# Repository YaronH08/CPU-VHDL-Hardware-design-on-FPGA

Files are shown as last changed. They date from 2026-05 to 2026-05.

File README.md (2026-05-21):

# Processor Architecture and RTL Design

## Overview

This repository contains an academic laboratory project focused on processor architecture, RTL design, and hardware description methodologies.

The lab demonstrates the design and analysis of core processor components, with emphasis on the relationship between the instruction set architecture, the datapath, and the control unit. The project was implemented as part of a Hardware Description Languages and FPGA-based digital design course.

The main goal of this lab was to gain practical experience in designing digital hardware at the RTL level and understanding how processor functionality is translated into hardware structures.

---

## Main Objectives

- Understand the basic structure of a processor core
- Study the relationship between ISA and microarchitecture
- Design processor components using RTL methodology
- Analyze the separation between datapath and control logic
- Perform functional simulation and verification
- Gain practical experience with hardware description languages

---

## Key Topics

- Hardware Description Languages
- RTL design methodology
- Processor architecture
- ISA and microarchitecture concepts
- Datapath design
- Control-unit logic
- Functional verification
- Testbench-based simulation

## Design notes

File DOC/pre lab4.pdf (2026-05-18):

# Preparation Report LAB4

## דביר חן סעד 214078792-

## ירון חדד- 316411057

## תוכן עניינים

בדיקת ביצועים | 3.

### סימולציה | 4-6

מציאת תדר מקסימלי | 7.
תיאור המערכת | 8-10.
הצגת הרכיבים RTL ומסלול קריטי | 10-16.
שימוש בסיגנלים | 17..

# מטרת המעבדה

במעבדה זו נלמד כיצד לבצע סינתזה עבור מודלים שאנו נפתח בעזרת תוכנת Quartus

ובפרט נשתמש במודל אשר פיתחנו במעבדה 1 ונוסיף לו עוד מודל סינכרוני אשר מוגדר

בהמשך.

את הסינתזה נבצע על FPGA v cyclone.

בנוסף למודל של מעבדה 1 התבקשנו להוסיף עוד מודל סינכורני אשר מייצר לנו גלי PWM לפי קוד הALU המבוקש.

את הרכיב ממישנוב בעזרת מונה)counter )ויחידה לוגית אשר אחראית למימוש הגלים.

להלן המודל אותו ממשנו בתמונה מס1

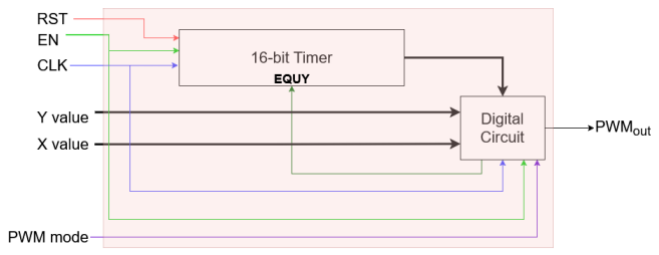
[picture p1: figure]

תמונה 1 מעטפת למודל הPWM

בדיקת ביצועים

בכדי לבדוק את הביצועים של המודל אשר פיתחנו במעבדה 1 אך בכדי לבצע סינתה נצטרך רכיב סינכרוני אך הרכיב של מעבדה 1 לא סינכרוני ולכן נוסיף באופן מלאכותי מערכת סינכרונית של רגיסטר כניסה ורגיסטר מוצא אשר הם יפעלו לפי אותו שעון.

כפי שמוצג בתמונה מס 2

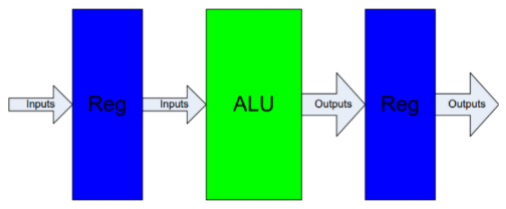
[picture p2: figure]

תמונה 2 מעטפת למודל הALU

כאשר אל הרגיסטרים מחובר השעון של הכרטיס -

signal name | FPGA Pin No | Description | I/O Standard
CLOCK_50 | PIN_AF14 | 50MHz clk input | 3.3V

Model-sim | סימולציית

### בסימולציה זו ניצור TB אשר יבדוק את המודל באופן פרטני עבור כל מודל כאשר

הכל עטוף במעטפת של הtop.

### נסתכל על מספר של בדיקות ונראה שאכן מתבצע כמצופה פעולת add

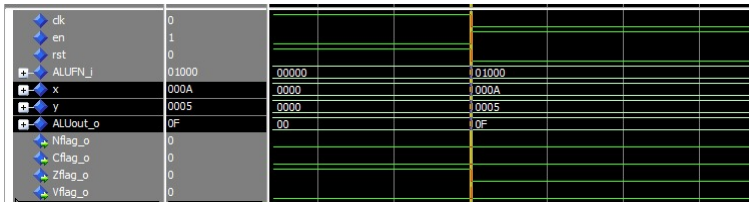
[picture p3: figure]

תמונה 3 תוצאת פעולת החיבור

### כפי שאנו רואים ערכי הרגיסטר X וערך הרגיסטר Y נסכמים ואכן אנו מקבלים את התוצאה הרצויה F=+5A כלומר 10+5=15

### פעולת Logic

תמונה 4 פעולת logic
אנו רואים כי קוד הפעולה 010 הינו פעולת הand ואנו רואים כי רק ביט הMSB והביט ה4 דולקים אצל שני הכניסות ואכן תוצאת הפעולה היא שיש 1 רק עבור 2 הביטים הנ"ל

### פעולת SHL

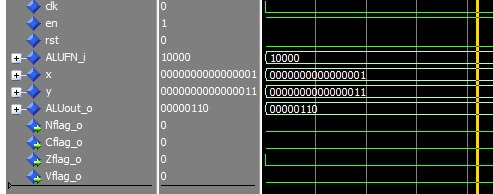
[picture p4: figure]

תמונה 5 תוצאת פעולת הזזה

### נשים לב כי אותות הכניסה הינם 1 ו3 כלומר ערך המוזז הינו 3 ואנו נצטרך לבצע הזזה אחת כלומר -011< 110 כלומר נצפה לקבל את הערך 6 ואכן המוצא הינו .6

### פעולת PWM

תמונה 6 תוצאת פעולת אות pwm

כפי שניתן לראות קוד הפעולה הינו 00001 כלומר כפי שהוגדר הגל אמור לעלות בערך y ולרדת כאשר אנו מגיעים לערך x
במצב שלנו c=y3,=x ואכן אנו רואים כי בזמן הגעת השעון לערך c האות עולה ל1 ונשאר על הערך 1 עד הגעת השעון לערך .3

## מציאת תדר מקסימלי

### בכדי למצוא את התדר המקסימלי של המערכת שלנו כמו שהזכרנו למעלה הוספנו 2

רגיסטרים בכניסה ובמוצא של מודל הalu. כעת נבצע קימפול וסינתזה של הרכיב כפי שמבוקש .

### לאחר הקימפול נוכל להכנס לTool ולאחר מכן לבחור את האופציה שלtimer ושם יש לנו את העמודה שמראה מהו התדר המקסימלי:

תמונה 7 מציאת התדר המקסימלי של המודל

לאחר שמצאנו את התדר הנ"ל נצטרך להציב אותו במערכת כדי ליצור חסם על התדר בכדי לא לחרוג מהמערכת וגם בכדי לא לבזבז הספק לחינם.

## תיאור המערכת

### המערכת שלנו מפוצלת ל2 חלקים נפרדים כאשר כל מודול מורכב מתתי רכיבים

כעת נפרק מה הלוגיקה של כל אחד מהם ונראה את הסינתזה שלהם בעזרת תוכנת | -
רכיב הSDC –רכיב סינכרוני אשר פועל בזמן של עליית שעון | -

### רכיב הalu – רכיב אסינכרוני אשר פועל ללא תלות בשעון

הQuartus.

## רכיב הALU

### נרצה לממש מערכת אשר מבצעת מספר של פעולות כאשר לכל פעולה יש קוד

פעולה ספציפי אשר מגדיר מתי נשתמש בה .

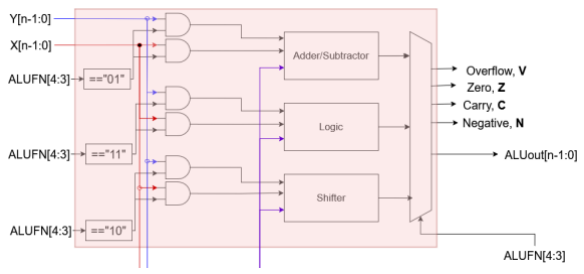
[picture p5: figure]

תמונה 8 מודל הALU
המודל מקבל 3 כניסות
- X- כניסה בעלת 16 ביטים
- Y -כניסה בעלת 16 ביטים
- ALUFN -קו בקרה בעל 5 סיביות שמגדיר את הפעולה שצריך לבצע

מוצאי המערכת הם:
- דגלים Nflag,Zflag,Vflag,Cflag- שמופעלים בהתאם לתוצאה של הפעולה שהתבצעה .
- ALUOUT מוצא בעל 16 סיביות שהוא התוצאה של הפעולה על x ועל y.

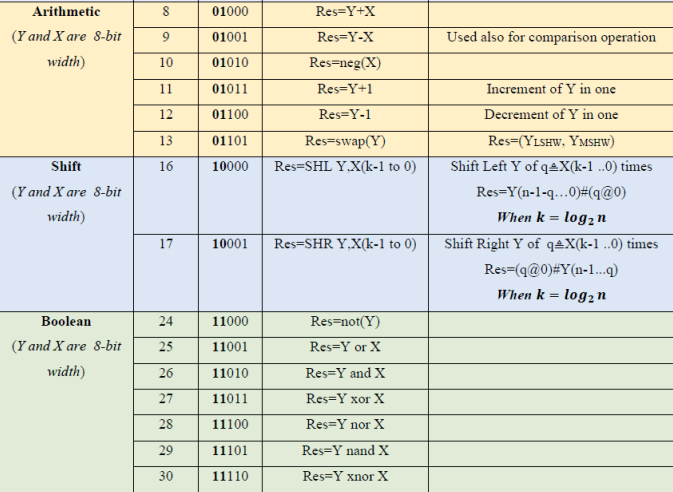
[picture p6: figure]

תמונה 9 הפעולות אשר ממושמות במודל שלALU

## רכיב הPWM

### רכיב בעל 6 כניסות

- X- כניסה בעלת 16 ביטים
- Y -כניסה בעלת 16 ביטים
- ALUFN -קו בקרה בעל 5 סיביות שמגדיר את הפעולה שצריך לבצע
- קוי בקרה Rst,En שאחראיים על תקפוד המערכת
- כניסת שעון clk

מוצאי המערכת הם:
- אות PWM שעליתו וירידתו הם כתוצאה מY,X וקוד הפעולה

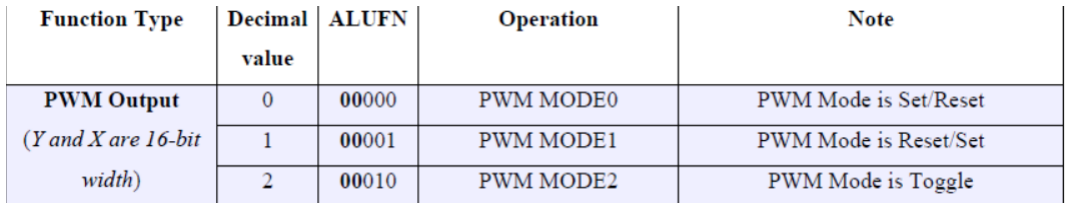
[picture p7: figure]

תמונה 10 הפעולות אשר ממושמות במודל שלPWM

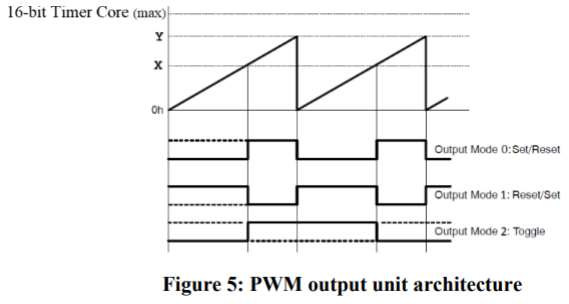
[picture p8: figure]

תמונה 11 סוגי הגלים אשר יוצאים מתוך המודולו כתלות בcounter

# שרטוט הRTL

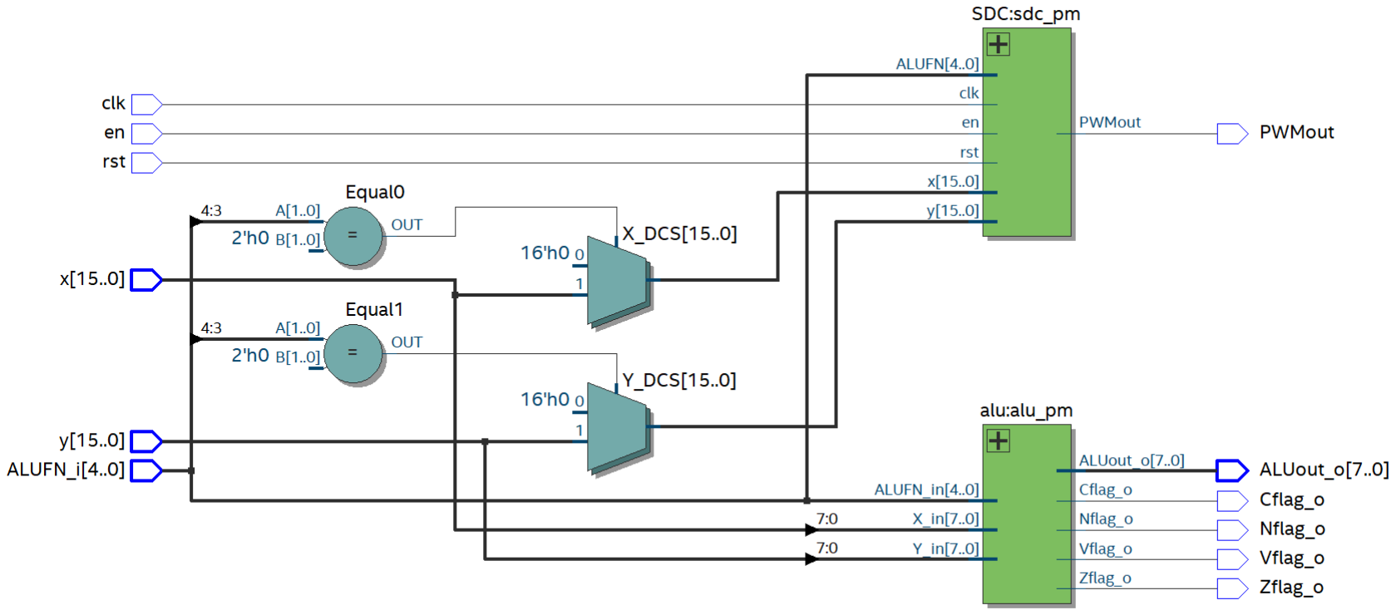
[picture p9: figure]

תמונה 11 RTL של המערכת הכוללת אפשר לראות שהמערכת מורכבת מ2 רכיבים אחד סינכרוני ואחד אסינכרוני כאשר יש mux שבורר בין 0 לערכי הכניסות וזה בכדי לשמור על בזבוז ההספק של המערכת. בזמן שהרכיב לא משומש נכנס הערכים 0000 בכל כניסה.

## רכיב AdderSub

רכיב זה מומש כבר במעבדה 1 ולכן רק נציג את התוספות שתורמת לנו התוכנה של הQuartus

## שרטוט הRTL

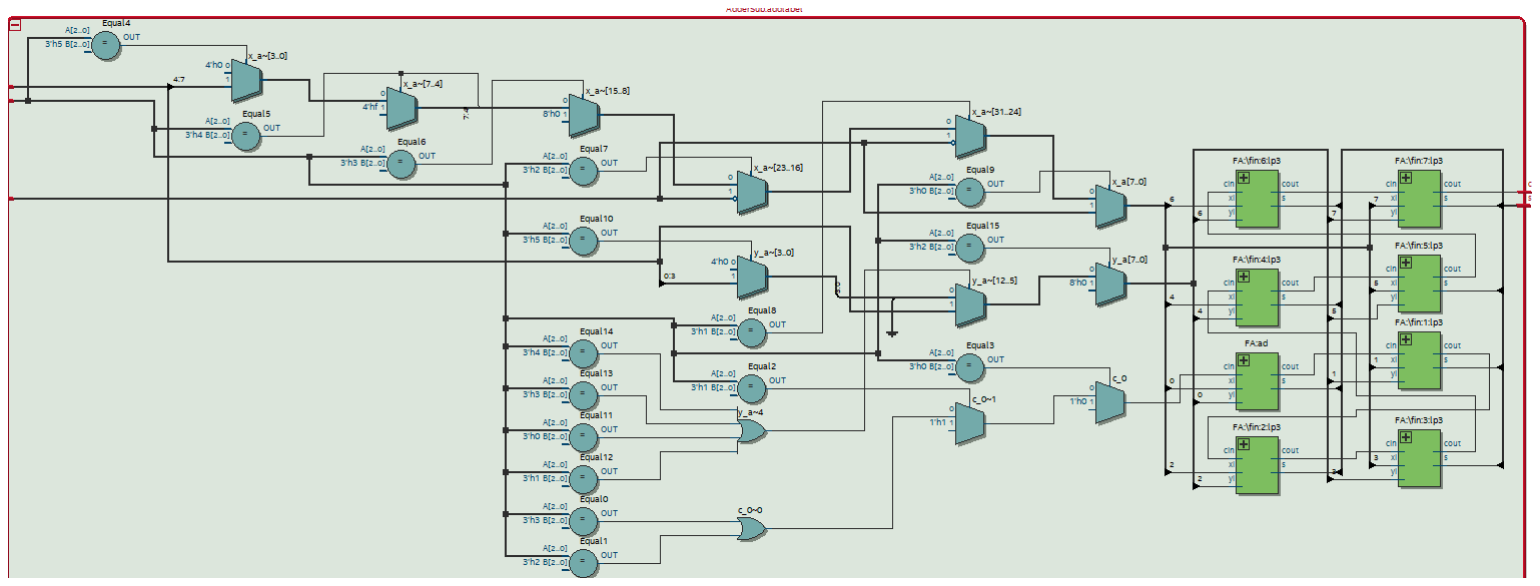
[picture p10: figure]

תמונה 12 RTL של הaddersub

## שימוש בלוגיקה כאשר פיתחנו את הקוד הלוגי אנו משתמשים באלמנטים הניתנים לקינפוג בהתאם לקוד הכתוב, בעזרת הקוארטוס בזמן תהליך הסינתזה אפשר להראות את הלוגיה של הרכיב:

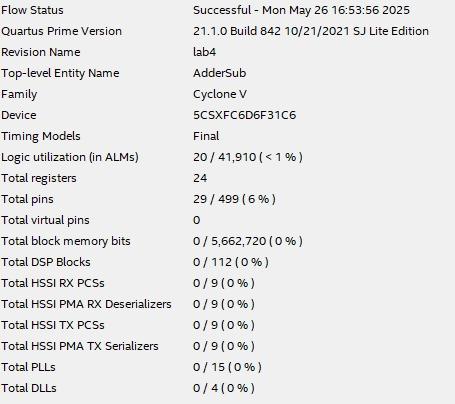
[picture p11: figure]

תמונה 13 לוגיה של הaddersub

## נתיב קריטי

הנתיב הקריטי חשוב ביותר מכיוון שהוא נותן לנו מידע על הזרימה של המידע וגם נותן לנו מגבלות עליה
מכיוון שלרכיבים יש השהייה עד להתייצבות הכניסות נצטרך לקחת זאת בחשבון להלן הנתיב הקריטי :

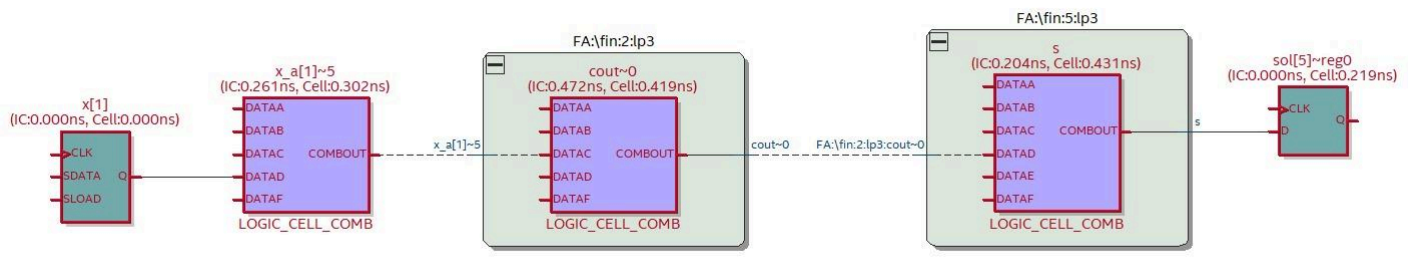
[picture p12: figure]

תמונה 14 נתיב קריטי של הaddersub

## רכיב Logic

רכיב זה מומש כבר במעבדה 1 ולכן רק נציג את התוספות שתורמת לנו התוכנה של הQuartus

## שרטוט הRTL

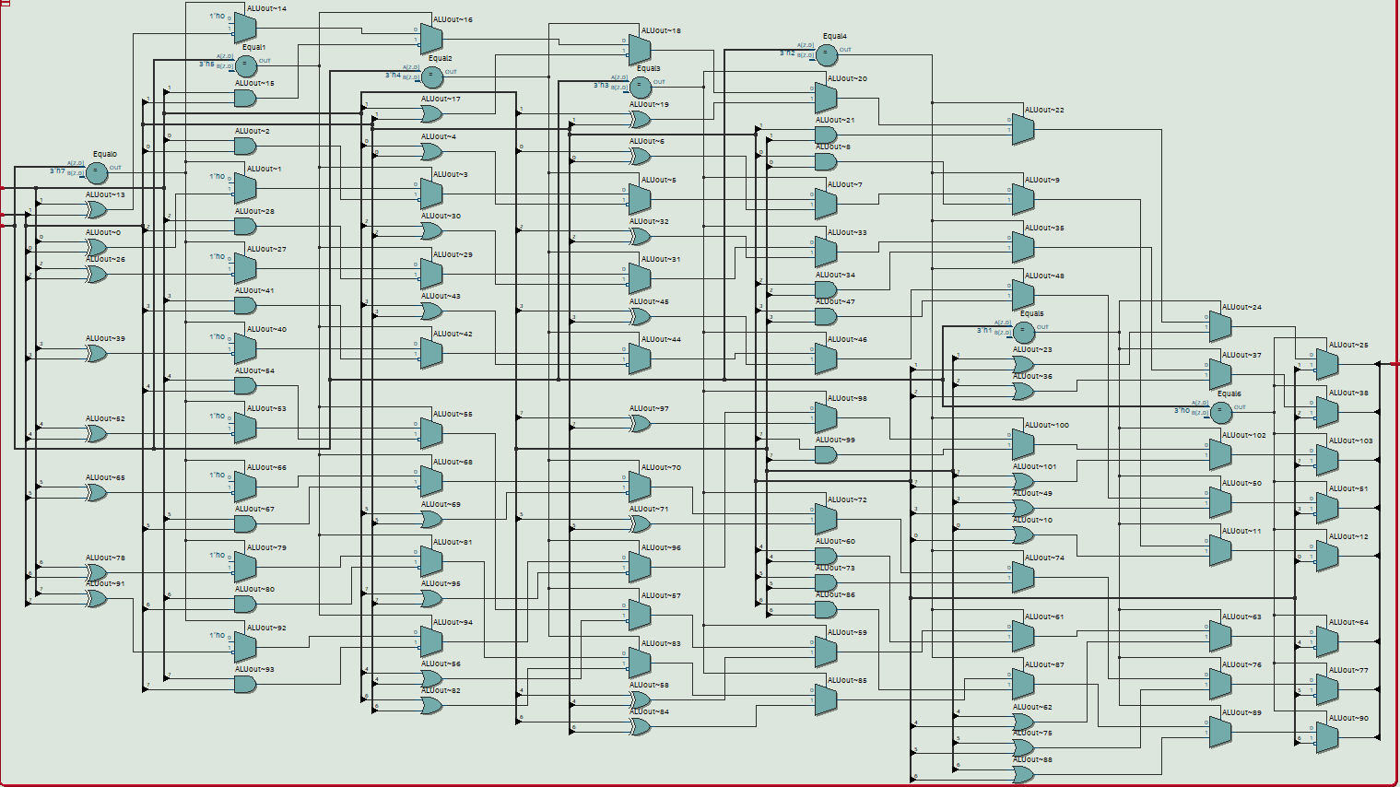
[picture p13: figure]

תמונה 15 RTL של הlogic

## שימוש בלוגיקה

כאשר פיתחנו את הקוד הלוגי אנו משתמשים באלמנטים הניתנים לקינפוג בהתאם לקוד הכתוב, בעזרת הקוארטוס בזמן תהליך הסינתזה אפשר להראות את הלוגיה של הרכיב:

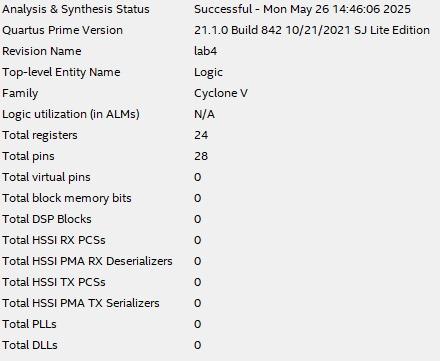
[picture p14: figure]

תמונה 16 לוגיה של logic

## נתיב קריטי

הנתיב הקריטי חשוב ביותר מכיוון שהוא נותן לנו מידע על הזרימה של המידע וגם נותן לנו מגבלות עליה
מכיוון שלרכיבים יש השהייה עד להתייצבות הכניסות נצטרך לקחת זאת בחשבון להלן הנתיב הקריטי :

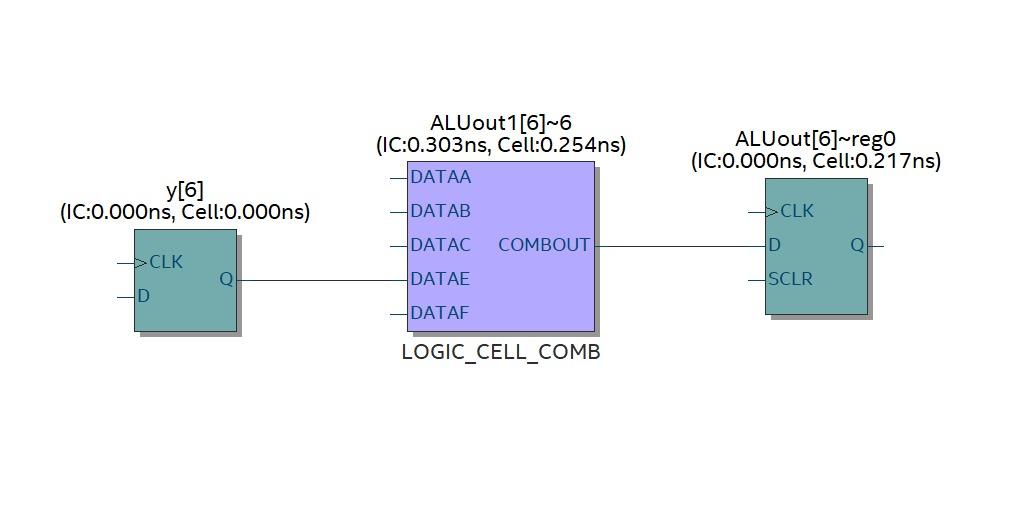
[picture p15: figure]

תמונה 17 נתיב קריטי של הlogic

## רכיב Shifter

רכיב זה מומש כבר במעבדה 1 ולכן רק נציג את התוספות שתורמת לנו התוכנה של הQuartus

## שרטוט הRTL

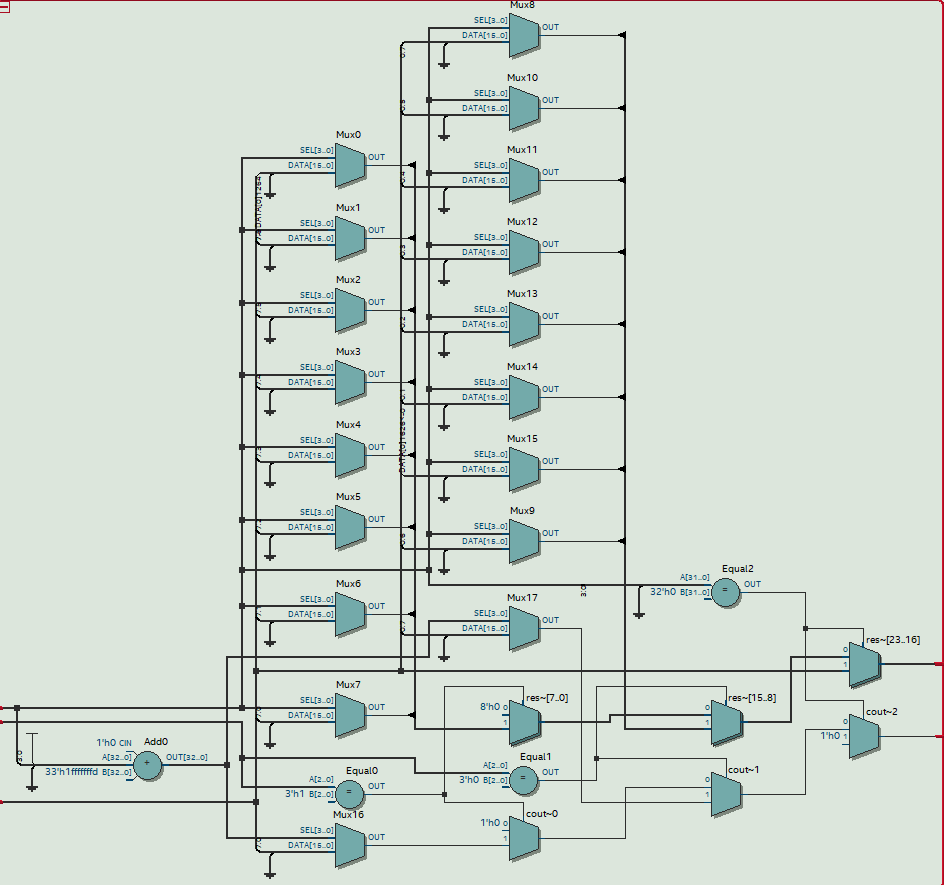
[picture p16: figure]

תמונה 18 RTL של הshifter

## שימוש בלוגיקה

כאשר פיתחנו את הקוד הלוגי אנו משתמשים באלמנטים הניתנים לקינפוג בהתאם לקוד הכתוב, בעזרת הקוארטוס בזמן תהליך הסינתזה אפשר להראות את הלוגיה של הרכיב:

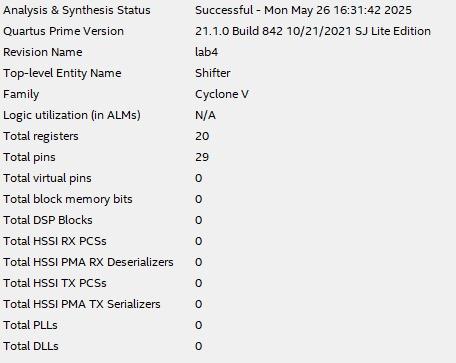
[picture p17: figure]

תמונה 19 לוגיה של shifter

## נתיב קריטי

הנתיב הקריטי חשוב ביותר מכיוון שהוא נותן לנו מידע על הזרימה של המידע וגם נותן לנו מגבלות עליה
מכיוון שלרכיבים יש השהייה עד להתייצבות הכניסות נצטרך לקחת זאת בחשבון להלן הנתיב הקריטי :

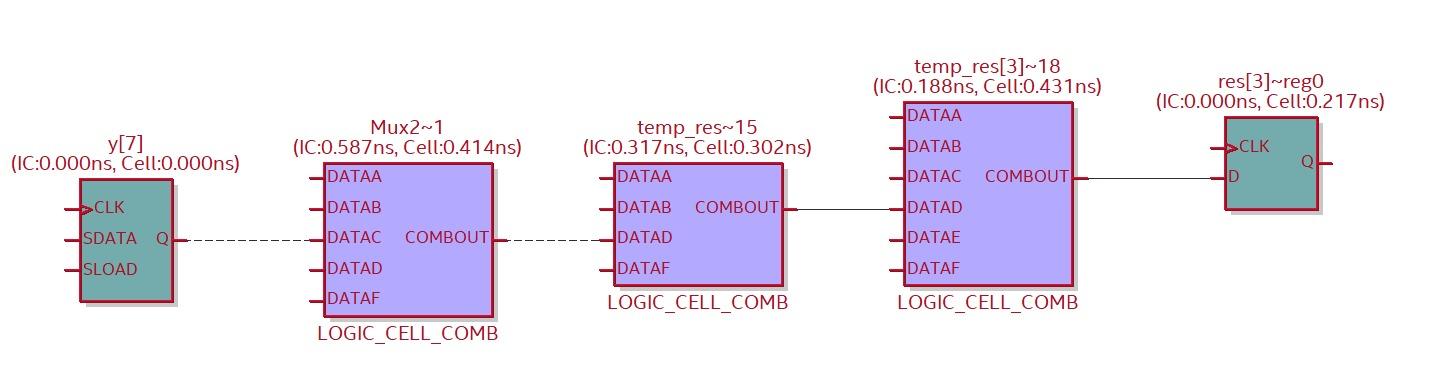
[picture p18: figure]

תמונה 20 נתיב קריטי של הshifter

## מסלול קריטי כלל ALU

נראה מהו המסלול הקריטי של כל יחידת הALU

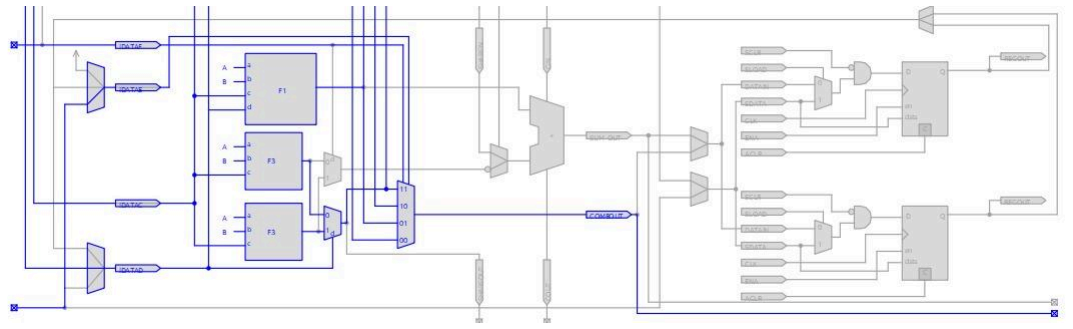
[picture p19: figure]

תמונה 21 נתיב קריטי של הalu

## רכיב הSDC

רכיב זה הוא רכיב סינכרוני אשר תלוי בשעון ואות כניסה en רכיב זה מורכב מ2 תתי רכיבים : -רכיב מנייה
רכיב המנייה בכל עליית שעון עולה עד לערך הy ובהגיעו לערך הוא מתאפס ומתחיל את המנייה | -

רכיב בקרה )control)

מחדש.

רכיב הבקרה מחליט על מצב הפעולה והוצאת המוצא למערכת ובמקביל נותן מידע לרכיב המנייה על הגעת המנייה לערך y.
שרטוט RTL

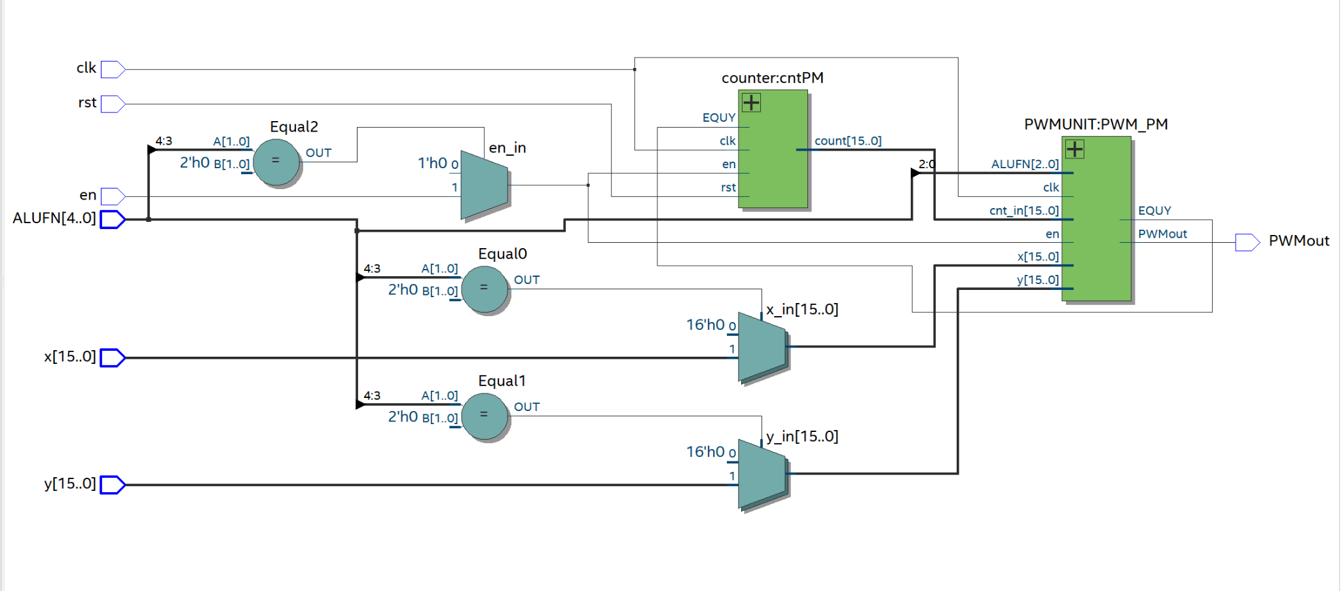
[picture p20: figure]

תמונה 22 RTL של רכיב סינכרוני

שימוש בלוגיקה
כאשר פיתחנו את הקוד הלוגי אנו משתמשים באלמנטים הניתנים לקינפוג בהתאם לקוד הכתוב, בעזרת הקוארטוס בזמן תהליך הסינתזה אפשר להראות את הלוגיה של הרכיב:

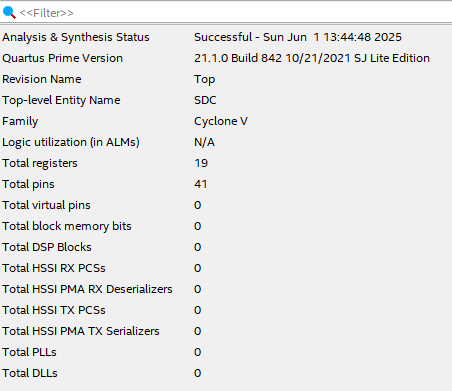
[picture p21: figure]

תמונה 23 לוגיקה של רכיב סינכרוני

## Signal Tap

נרצה לבצע וריפיקציה של החומרה על ידי שימוש בתוכנת הtap-signal שמובנת בתוך תוכנה הquartus.
בזמן אמת נוכל לתפוס את השינוי בפעולה על ידי בקשה של edge falling על גבי 2key שהוא יהיה הטריגר עצירה שלנו

הכנסנו את הסיגנלים של הleds בכדי לעקוב אחרי הopc של המערכת הוספנו גם את רגיסטרים y,x ואת רגיסטר המוצא כדי לעקוב אחר התוצאה ולראות שכן התוצאה נכונה.

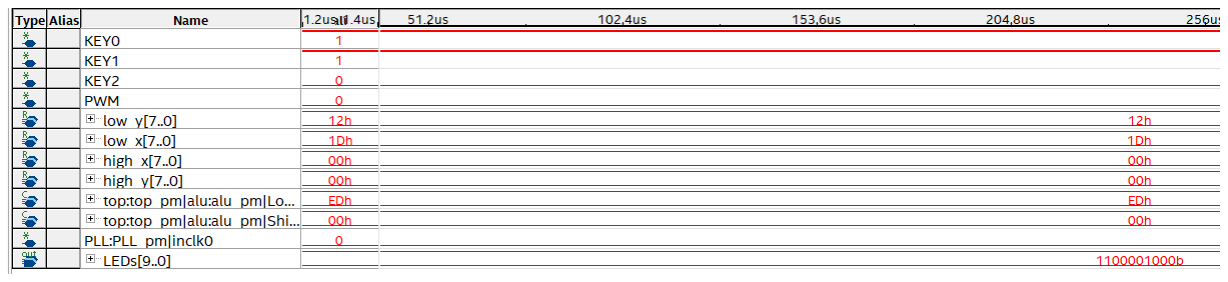
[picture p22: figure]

תמונה 24 פעולת or על y,x

מעבדה מהנה סהכ

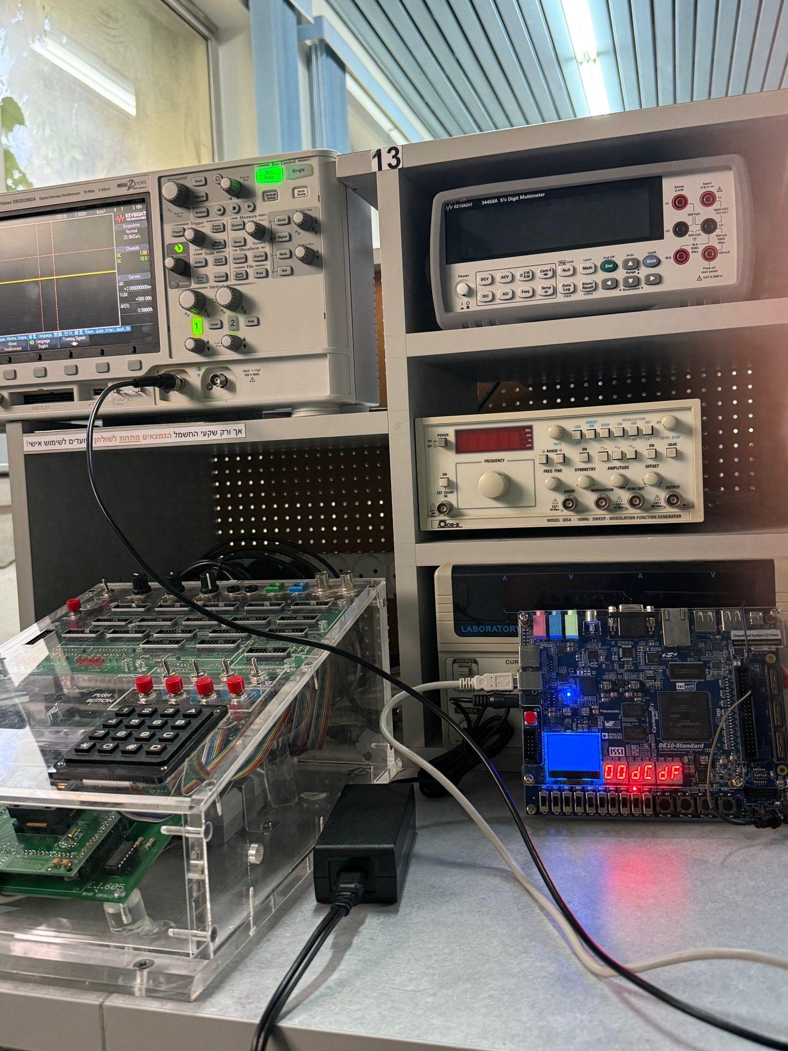
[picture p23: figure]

תמונה 25 הליכה לבדוק את פעולה pwm

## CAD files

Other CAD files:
quartus/db/stp1_auto_stripped.stp
quartus/RT.stp
quartus/db/RT_auto_stripped.stp
quartus/stp2.stp
quartus/db/stp2_auto_stripped.stp
quartus/stp1.stp
quartus/db/signaltap_auto_stripped.stp
